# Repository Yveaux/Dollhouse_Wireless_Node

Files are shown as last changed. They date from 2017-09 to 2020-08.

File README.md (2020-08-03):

# Dollhouse Wireless nRF24 MySensors IoT node

This sensor node was designed to be used in the MySensors dollhouse display, created for the [Eindhoven Maker Faire 2017](http://www.eindhovenmakerfaire.nl)

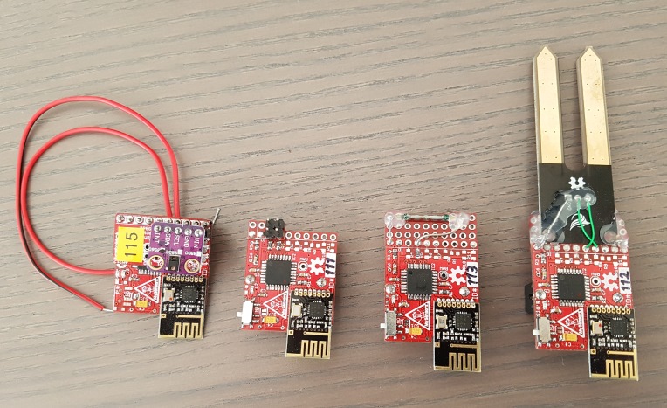
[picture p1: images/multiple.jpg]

Left-to-right: gesture sensor, door sensor, wind sensor, soil moisture sensor

Original requirements
========
* Very small, so it can be mounted visible in the house without distracting too much 
* 5V supply, or battery powered (CR2032)
* runs at 3V3
* nRF24L01+, SMD version
* 8MHz, internal oscillator
* Optional buffer cap (47..100uF) for battery node
* ATMega328; cheap, stay close to well known Arduino UNO/Pro mini
* ISP connector; small, ProtoProg
* Serial connector; small, pogo pins, GND, RX, TX, DTR (reset)
* At least 1 sensor per node
* On/off switch (for battery sensors)
* Application LED (Pin 4)
* Power LED (d.n.p. for battery sensor)
* IO to support sensors

The resulting node is very small (28.5 x 25.5mm, excluding antenna) and costs roughly E4,30/piece (excluding sensor)

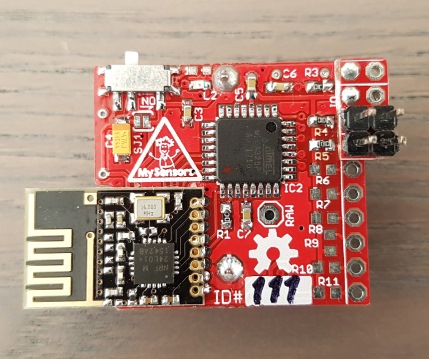
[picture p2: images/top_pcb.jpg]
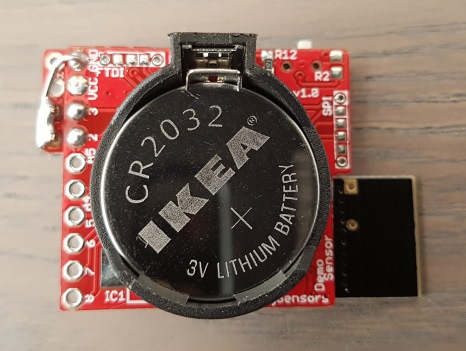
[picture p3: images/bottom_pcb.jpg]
 

Layout
========
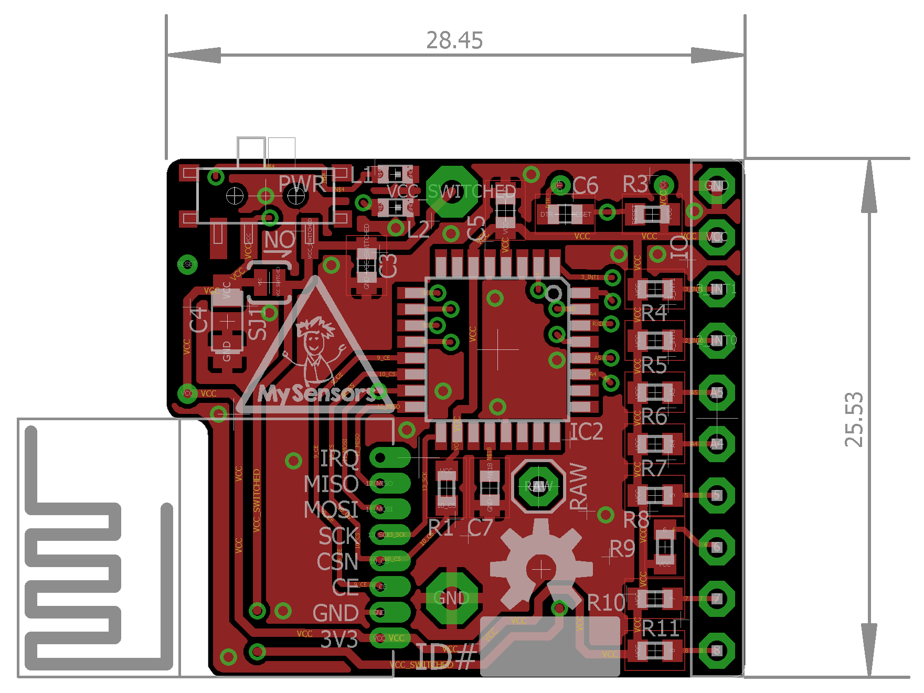
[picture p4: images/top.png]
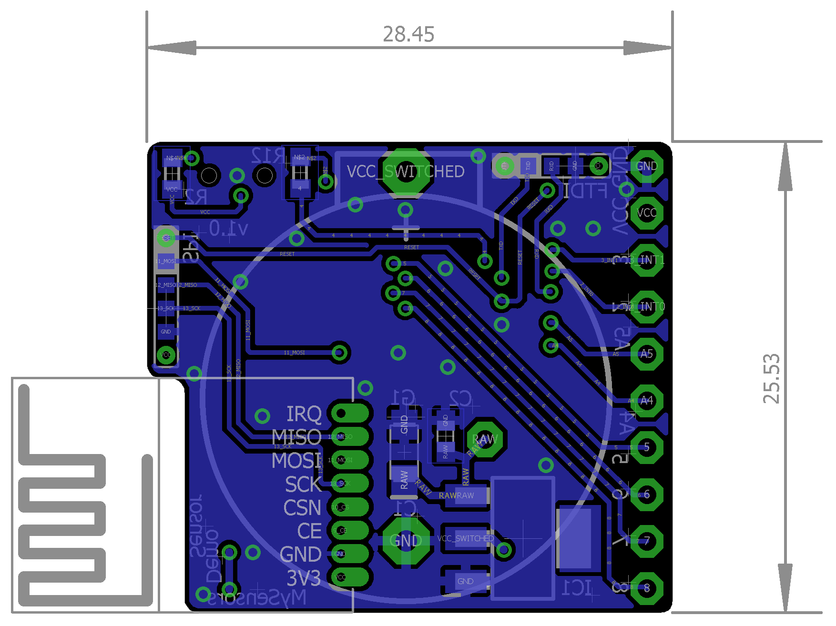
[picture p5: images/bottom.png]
 

Addon connector pinout
========
| Pin  | Arduino Pin | Alternate Function |
| ---- | --- | --- |
| 1 | GND | | |
| 2 | VCC |
| 3 | 3 | INT1 |
| 4 | 2 | INT0 |
| 5 | A5 | I2C SCL |
| 6 | A4 | I2C SDA |
| 7 | 5 | |
| 8 | 6 | |
| 9 | 7 | |
| 10 | 8 | |

Pin 1 is next to the FTDI pogo pin connector.

Addon board
========
I created a small addon board to simplify connecting a numer of standard sensors. It can be mounted on the IO connector using male headers.
Supported sensors/actuators:
* 2 servo's
* AM312 Mini PIR
* BME280 Temperature, relative humidty & pressure sensor
* APDS9930 Digital Ambient Light and Proximity Sensor
* APDS9960 RGB & gesture sensor
Please make sure to verify the pinout and supply level of a module before connecting it to the addon board!

Addon proto board
========
Small 10 x 4 proto board to connect other sensors (e.g. the soil humidity & wind-speed reed sensor)

Construction
========
Start with the ATMega, followed by the small SMD's on the top and nRF24. Flip the board and mount either the CR2032 holder, or the AMS1117-3V3.

The switch is optional. Either mount the switch or short solder jumper SJ1.

Mount the power LED (and its resistor R2) if you prefer a visible indication of a node being switched on. Do not mount it on a CR2032 powered sleeping node as it will drain the battery too quickly.

Pull-up resistors R4-R11 can be used for digital inputs to further reduce the power drain. Mount approx. 1Meg ohm and disable internal pullups.

When powered from a 5V supply (and AMS1117 mounted) use the RAW and GND pins to power the board.

Programming
========
To keep the sensor small the ISP and FTDI connectors are scaled down to use pogo pins for programming.
ISP programming requires a [ProtoProg](http://protofusion.org/wordpress/2013/05/open-hardware-pogo-pin-programmer/) adapter.

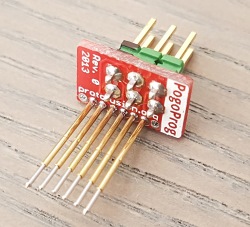
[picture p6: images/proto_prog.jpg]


To flash the bootloader refer to my [Ikea Molgan Hack](https://github.com/Yveaux/Ikea_Molgan_Hack)

The serial connection used by the Arduino IDE is available at a 5 pin FTDI-to-pogo adapter, also included in this repository. Make sure to align the white pin on the adapter to the white pin on the board. I use the node's power when programming at 3V3 serial levels.

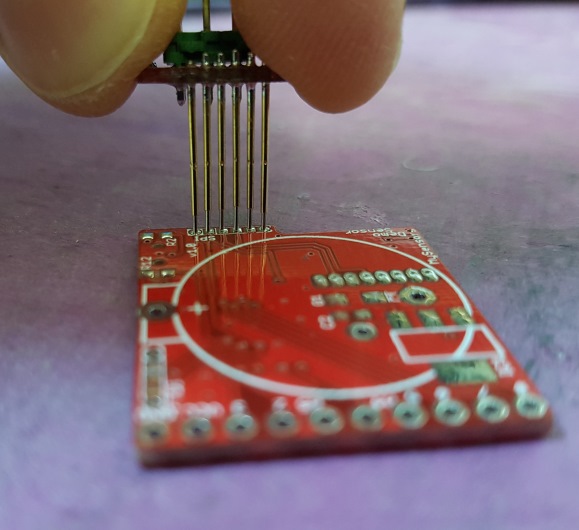
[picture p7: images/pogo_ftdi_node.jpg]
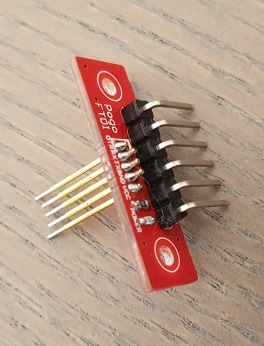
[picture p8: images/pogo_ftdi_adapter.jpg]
 

Known issues
========
* The buffer capacitor C4 is located after the switch. Powering off a sleeping sensor will take some to actually shut down the sensor as the buffer capacitor will still supply the ATMega for some time.

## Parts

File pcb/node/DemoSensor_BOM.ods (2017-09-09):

Part | Value | Device | Package | Description | Remark | Source
C1 | 10uF | CPOL-EUSMCA | SMC_A | POLARIZED CAPACITOR | Only mount for 5V supply
C2 | 100nF | C-EUC0603 | C0603 | CAPACITOR | Only mount for 5V supply
C3 | 100nF | C-EUC0603 | C0603 | CAPACITOR | Only mount for 5V supply
C4 | 47uF | CPOL-EUSMCA | SMC_A | POLARIZED CAPACITOR
C5 | 100nF | C-EUC0603 | C0603 | CAPACITOR
C6 | 100nF | C-EUC0603 | C0603 | CAPACITOR
C7 | 100nF | C-EUC0603 | C0603 | CAPACITOR
G1 | CR2032H | CR2032H | CR2032H | LI BATTERY Varta | Only mount for CR2032 supply | https://www.aliexpress.com/item/Hot-Sale-10pcs-lot-CR2032-CR2025-Battery-Holder-Original-Batteries-Button-Cell-Holder-Socket-Case-Free/32476465581.html
IC1 |  | V_REG_LM1117SOT223 | SOT223 | Voltage Regulator LM1117 | Only mount for 5V supply
IC2 | MEGA328P-AU | MEGA48/88/168-AU | TQFP32-08
L1 |  | LEDCHIPLED_0603 | CHIPLED_0603 | LED | Power LED. Optional. Do not mount for battery sensors!
L2 |  | LEDCHIPLED_0603 | CHIPLED_0603 | LED
M1 | WIRELESS-NRF24L01SMD2 | WIRELESS-NRF24L01SMD2 | WIRELESS-NRF24L01-SMD-2 | 2.4 GHz Wireless Module based on NRF24L01 chip
PWR | MSK-12C02_SMD_SPDT_SWITCH | MSK-12C02_SMD_SPDT_SWITCH | MSK-12C02 | Footprint of the VIMEX MSK-12C02 SPDT SMD Switch | Optional. Mount if you prefer a switch | https://www.aliexpress.com/item/100PCS-MSK-12C01-07-1P2T-7-foot-SMT-SMD-Stubbs-2-Position-Power-Mico-Switch/32703634956.html
R1 | 10k | R-EU_R0603 | R0603 | RESISTOR
R2 | 56 | R-EU_R0603 | R0603 | RESISTOR
R3 | 10k | R-EU_R0603 | R0603 | RESISTOR
R4 |  | R-EU_R0603 | R0603 | RESISTOR | Optional pullup resistor
R5 |  | R-EU_R0603 | R0603 | RESISTOR | Optional pullup resistor
R6 |  | R-EU_R0603 | R0603 | RESISTOR | Optional pullup resistor
R7 |  | R-EU_R0603 | R0603 | RESISTOR | Optional pullup resistor
R8 |  | R-EU_R0603 | R0603 | RESISTOR | Optional pullup resistor
R9 |  | R-EU_R0603 | R0603 | RESISTOR | Optional pullup resistor
R10 |  | R-EU_R0603 | R0603 | RESISTOR | Optional pullup resistor
R11 |  | R-EU_R0603 | R0603 | RESISTOR | Optional pullup resistor
R12 | 56 | R-EU_R0603 | R0603 | RESISTOR

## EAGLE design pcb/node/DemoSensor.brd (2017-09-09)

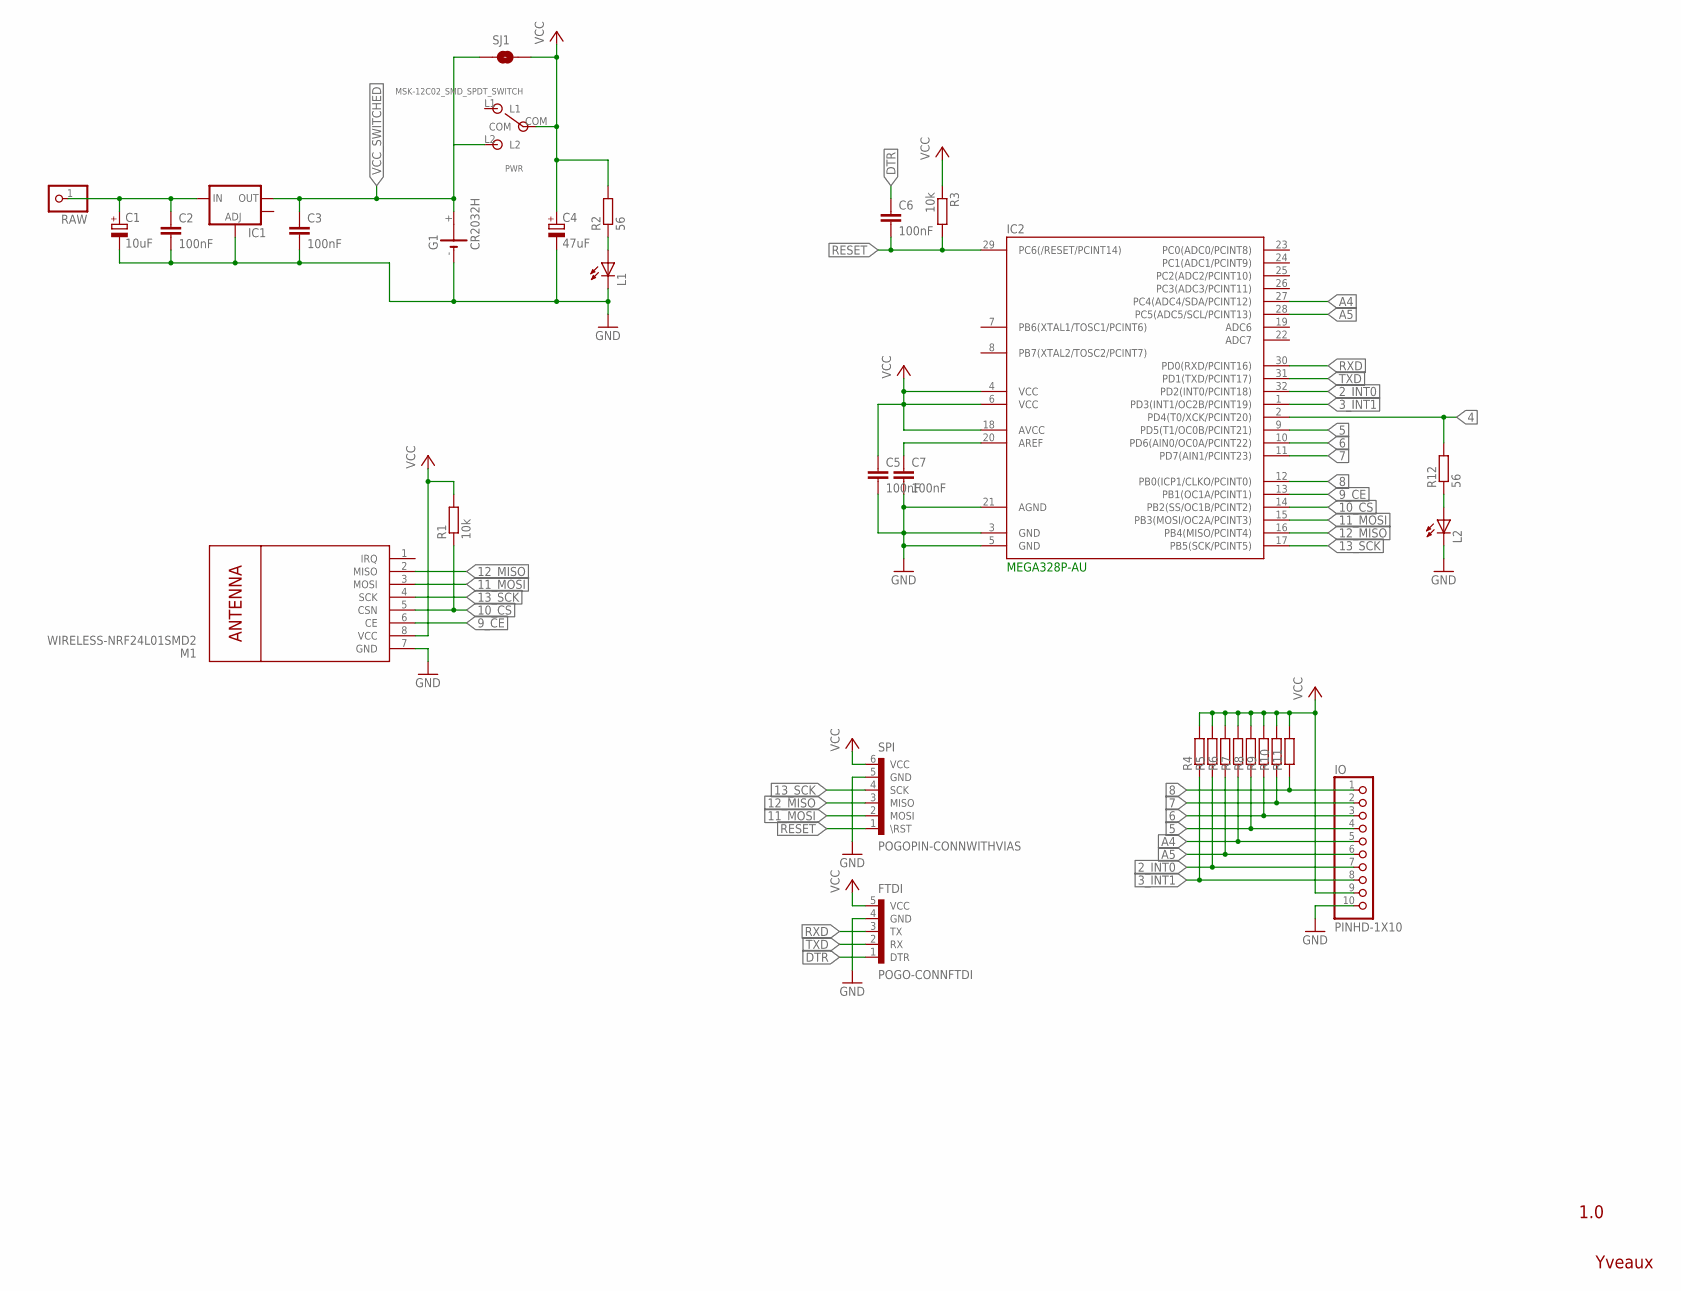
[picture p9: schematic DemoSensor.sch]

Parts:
C1: 10uF; SMC_A
C2, C3, C5, C6, C7: 100nF; C0603
C4: 47uF; SMC_A
FTDI: POGO-CONNFTDI; POGO5-VIAS
G1: CR2032H
IC1: V_REG_LM1117SOT223; SOT223
IC2: MEGA328P-AU; TQFP32-08
IO: PINHD-1X10; 1X10-BIG
L1, L2: LEDCHIPLED_0603; CHIPLED_0603
M1: WIRELESS-NRF24L01SMD2; WIRELESS-NRF24L01-SMD-2
PWR: MSK-12C02_SMD_SPDT_SWITCH; MSK-12C02
R1, R3: 10k; R0603
R2, R12: 56; R0603
R4, R5, R6, R7, R8, R9, R10, R11: R-EU_R0603; R0603
RAW: PINHD-1X1; 1X01
SJ1: SOLDERJUMPERNO; SJ_2S-NO
SPI: POGOPIN-CONNWITHVIAS; POGOPROG-CONN-0H

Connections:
2_INT0: IC2.32 (PD2(INT0/PCINT18)), IO.7, R5.1
3_INT1: IC2.1 (PD3(INT1/OC2B/PCINT19)), IO.8, R4.1
4: IC2.2 (PD4(T0/XCK/PCINT20)), R12.2
5: IC2.9 (PD5(T1/OC0B/PCINT21)), IO.4, R8.1
6: IC2.10 (PD6(AIN0/OC0A/PCINT22)), IO.3, R9.1
7: IC2.11 (PD7(AIN1/PCINT23)), IO.2, R10.1
8: IC2.12 (PB0(ICP1/CLKO/PCINT0)), IO.1, R11.1
9_CE: IC2.13 (PB1(OC1A/PCINT1)), M1.6 (CE)
10_CS: IC2.14 (PB2(SS/OC1B/PCINT2)), M1.5 (CSN), R1.1
11_MOSI: IC2.15 (PB3(MOSI/OC2A/PCINT3)), M1.3 (MOSI), SPI.2 (MOSI)
12_MISO: IC2.16 (PB4(MISO/PCINT4)), M1.2 (MISO), SPI.3 (MISO)
13_SCK: IC2.17 (PB5(SCK/PCINT5)), M1.4 (SCK), SPI.4 (SCK)
A4: IC2.27 (PC4(ADC4/SDA/PCINT12)), IO.5, R7.1
A5: IC2.28 (PC5(ADC5/SCL/PCINT13)), IO.6, R6.1
DTR: C6.1, FTDI.1 (DTR)
GND: C1.-, C2.2, C3.2, C4.-, C5.2, C7.2, FTDI.4 (GND), G1.-, IC1.1 (ADJ), IC2.3 (GND), IC2.5 (GND), IC2.21 (AGND), IO.10, L1.C, L2.C, M1.7 (GND), SPI.5 (GND)
unnamed: L2.A, R12.1
unnamed: L1.A, R2.1
unnamed: C7.1, IC2.20 (AREF)
RAW: C1.+, C2.1, IC1.3 (IN), RAW.1
RESET: C6.2, IC2.29 (PC6(/RESET/PCINT14)), R3.2, SPI.1 (\RST)
RXD: FTDI.3 (TX), IC2.30 (PD0(RXD/PCINT16))
TXD: FTDI.2 (RX), IC2.31 (PD1(TXD/PCINT17))
VCC: C4.+, C5.1, FTDI.5 (VCC), IC2.4 (VCC), IC2.6 (VCC), IC2.18 (AVCC), IO.9, M1.8 (VCC), PWR.COM, R1.2, R2.2, R3.1, R4.2, R5.2, R6.2, R7.2, R8.2, R9.2, R10.2, R11.2, SJ1.2, SPI.6 (VCC)
VCC_SWITCHED: C3.1, G1.+, IC1.2 (OUT), PWR.L2, SJ1.1

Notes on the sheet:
1.0
Yveaux

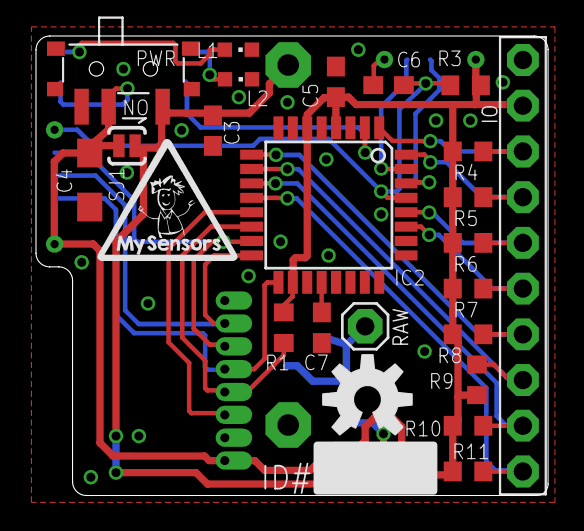
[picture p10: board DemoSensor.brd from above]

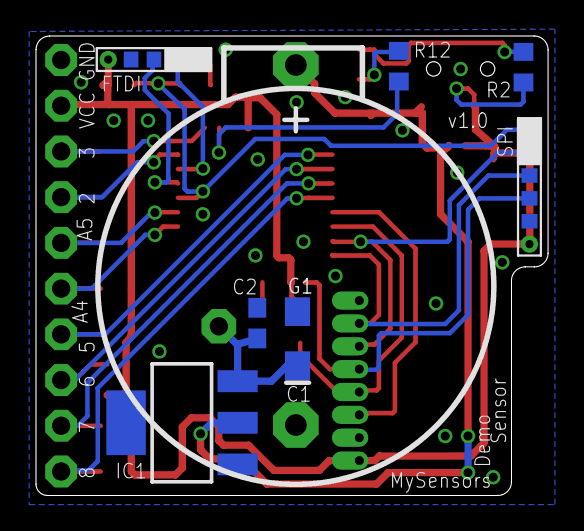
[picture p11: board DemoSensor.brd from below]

Board: 2 copper layers, 28.4 x 25.5 mm, 33 parts (8 on the bottom side), 25 nets.

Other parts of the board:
U$5: OSHW-LOGO-M
U$6: STICKER_8MM

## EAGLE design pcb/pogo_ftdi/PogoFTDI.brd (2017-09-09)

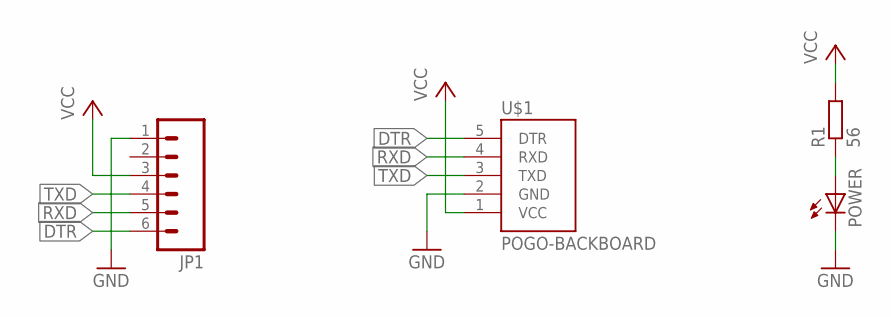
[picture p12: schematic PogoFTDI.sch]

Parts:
JP1: M06SIP; 1X06
POWER: LEDCHIPLED_0603; CHIPLED_0603
R1: 56; R0603
U$1: POGO-BACKBOARD; POGO5-BACKMOUNT

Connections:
DTR: JP1.6, U$1.5 (DTR)
GND: JP1.1, POWER.C, U$1.2 (GND)
unnamed: POWER.A, R1.1
RXD: JP1.5, U$1.4 (RXD)
TXD: JP1.4, U$1.3 (TXD)
VCC: JP1.3, R1.2, U$1.1 (VCC)

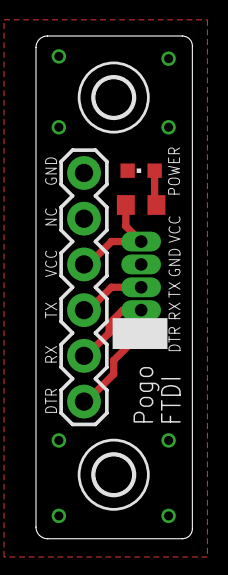
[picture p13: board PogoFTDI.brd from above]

Board: 2 copper layers, 8.7 x 27.9 mm, 6 parts (0 on the bottom side), 6 nets.

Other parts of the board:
U$2, U$3: HOLE_M2PAN_TIGHT

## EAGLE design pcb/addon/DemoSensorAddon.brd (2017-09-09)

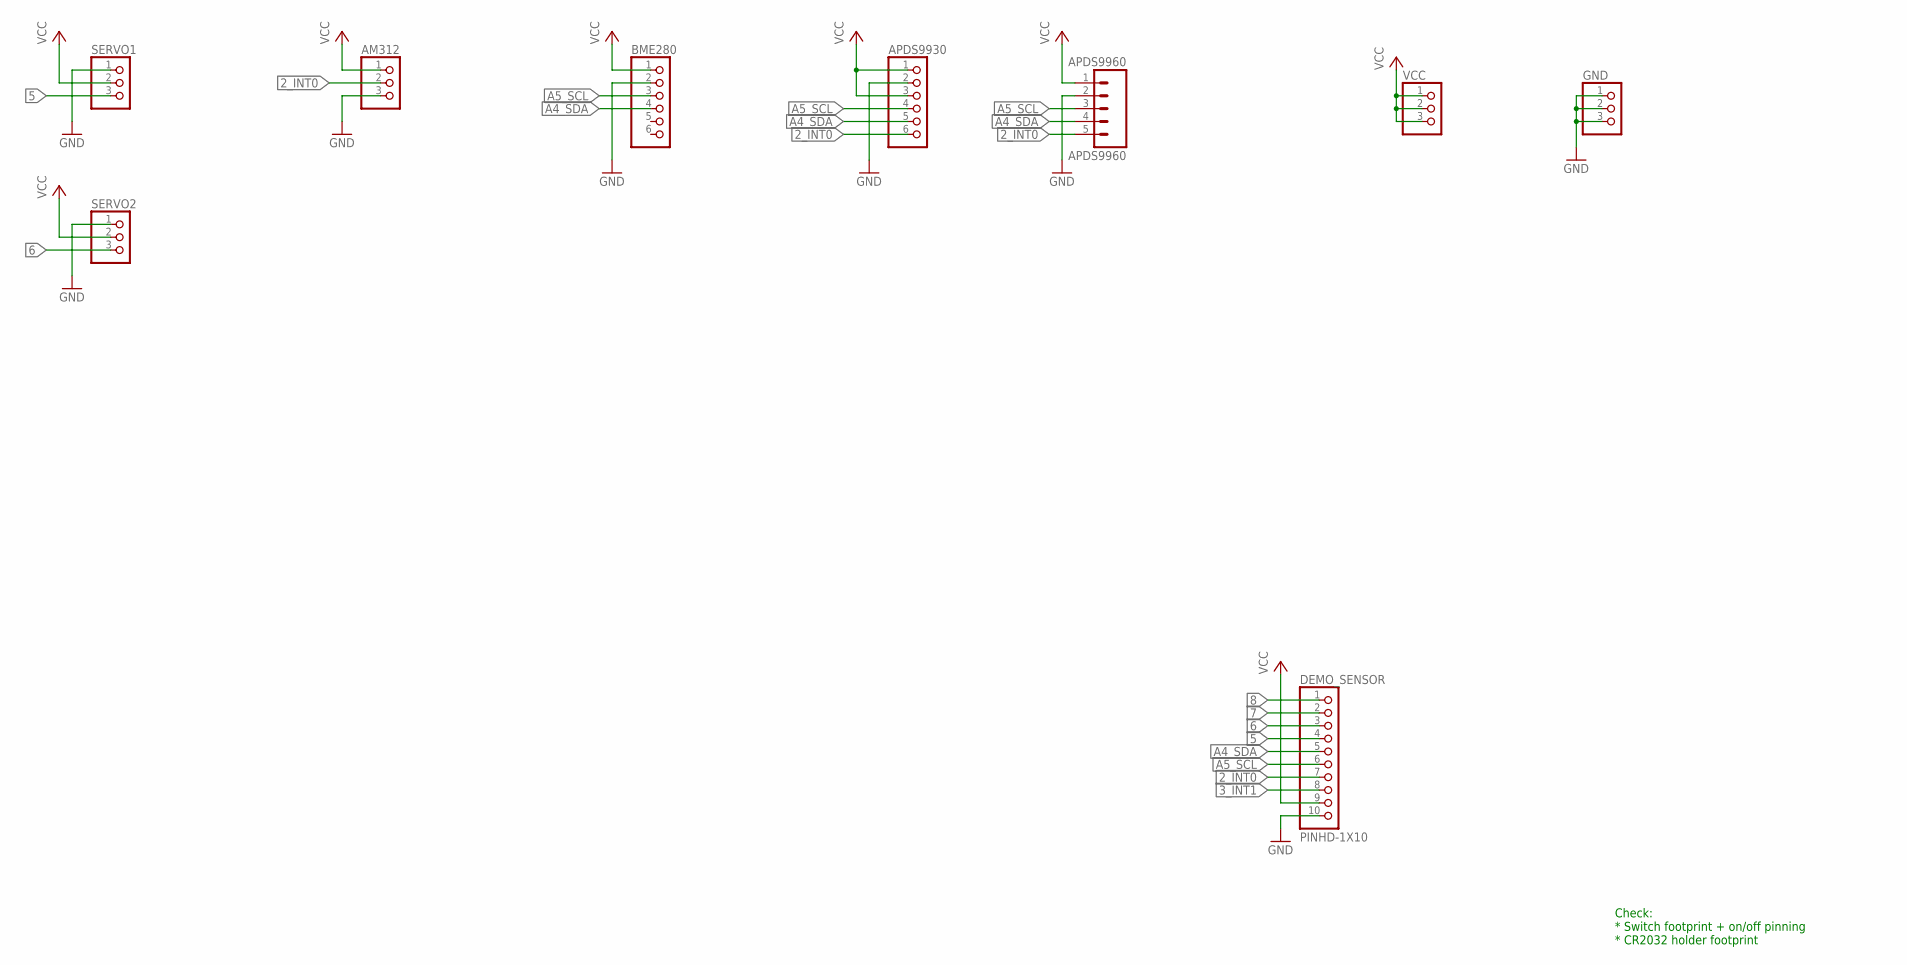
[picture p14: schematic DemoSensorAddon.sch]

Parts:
AM312: PINHD-1X3; 1X03
APDS9930: PINHD-1X6; 1X06
APDS9960: APDS9960; 1X05
BME280: PINHD-1X6; 1X06
DEMO_SENSOR: PINHD-1X10; 1X10-BIG
GND: PINHD-1X3; 1X03
SERVO1, SERVO2: PINHD-1X3; 1X03
VCC: PINHD-1X3; 1X03

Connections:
2_INT0: AM312.2, APDS9930.6, APDS9960.5, DEMO_SENSOR.7
3_INT1: DEMO_SENSOR.8
5: DEMO_SENSOR.4, SERVO1.3
6: DEMO_SENSOR.3, SERVO2.3
7: DEMO_SENSOR.2
8: DEMO_SENSOR.1
A4_SDA: APDS9930.5, APDS9960.4, BME280.4, DEMO_SENSOR.5
A5_SCL: APDS9930.4, APDS9960.3, BME280.3, DEMO_SENSOR.6
GND: AM312.3, APDS9930.2, APDS9960.2, BME280.2, DEMO_SENSOR.10, GND.1, GND.2, GND.3, SERVO1.1, SERVO2.1
VCC: AM312.1, APDS9930.1, APDS9930.3, APDS9960.1, BME280.1, DEMO_SENSOR.9, SERVO1.2, SERVO2.2, VCC.1, VCC.2, VCC.3

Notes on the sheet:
Check: * Switch footprint + on/off pinning * CR2032 holder footprint

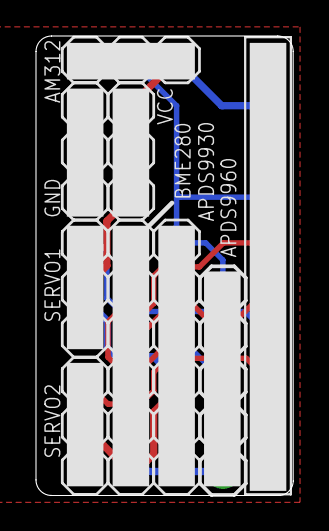
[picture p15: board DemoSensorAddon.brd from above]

Board: 2 copper layers, 14.3 x 25.5 mm, 9 parts (0 on the bottom side), 7 nets.

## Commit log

2017-09-09 Add design files & gerbers
    [DemoSensor.GBL, DemoSensor.GBO, DemoSensor.GBP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]
2017-09-09 Scaled bottom pcb image
2017-09-09 Added BOM
    [DemoSensor_BOM.ods]
2020-08-03 Fix pin 2 & 3 swap

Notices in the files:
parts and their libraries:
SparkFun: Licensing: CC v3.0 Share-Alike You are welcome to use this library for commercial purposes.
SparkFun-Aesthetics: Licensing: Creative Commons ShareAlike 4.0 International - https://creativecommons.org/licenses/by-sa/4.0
